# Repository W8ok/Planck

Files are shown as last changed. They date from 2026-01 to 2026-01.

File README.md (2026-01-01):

## Planck - My tiny programmable blinking LED circuit

My autism decided to get into homebrew computing, but i didnt know where to start with actual circuits.  
So I decided to go as simple as possible while keeping it pretty.  
This idea lead to this project and its future comings.  
The plan was to make a series of projects to slowly expand on making small "computer" systems with simple building blocks.  
For this first project those building blocks was just discrete components.  

The circuit is made from a simple clock running at about 1Hz feeding into two D-Flipflops acting as a 2-bit counter.  
This 2-bit output is fed into a multiplexer circuit which then provides power to the corresponding 4-bit diode-matrix ROM.  
The ROM is programmed by inserting diodes in specific positions to create the desired LED blink pattern.  
All in all, a splendid little passion project of mine.  

# Goals
Make a simple system using discrete components to program an LED blink sequence.  
Build it up on a PCB of some kind to hang on my wall for pretty kinetic art.  

# Status
Circuit - Finished  
PCB - Finished example (May make a better one eventually)  
Physical build - No (Only done on breadboard during design phase)  

# Schematic
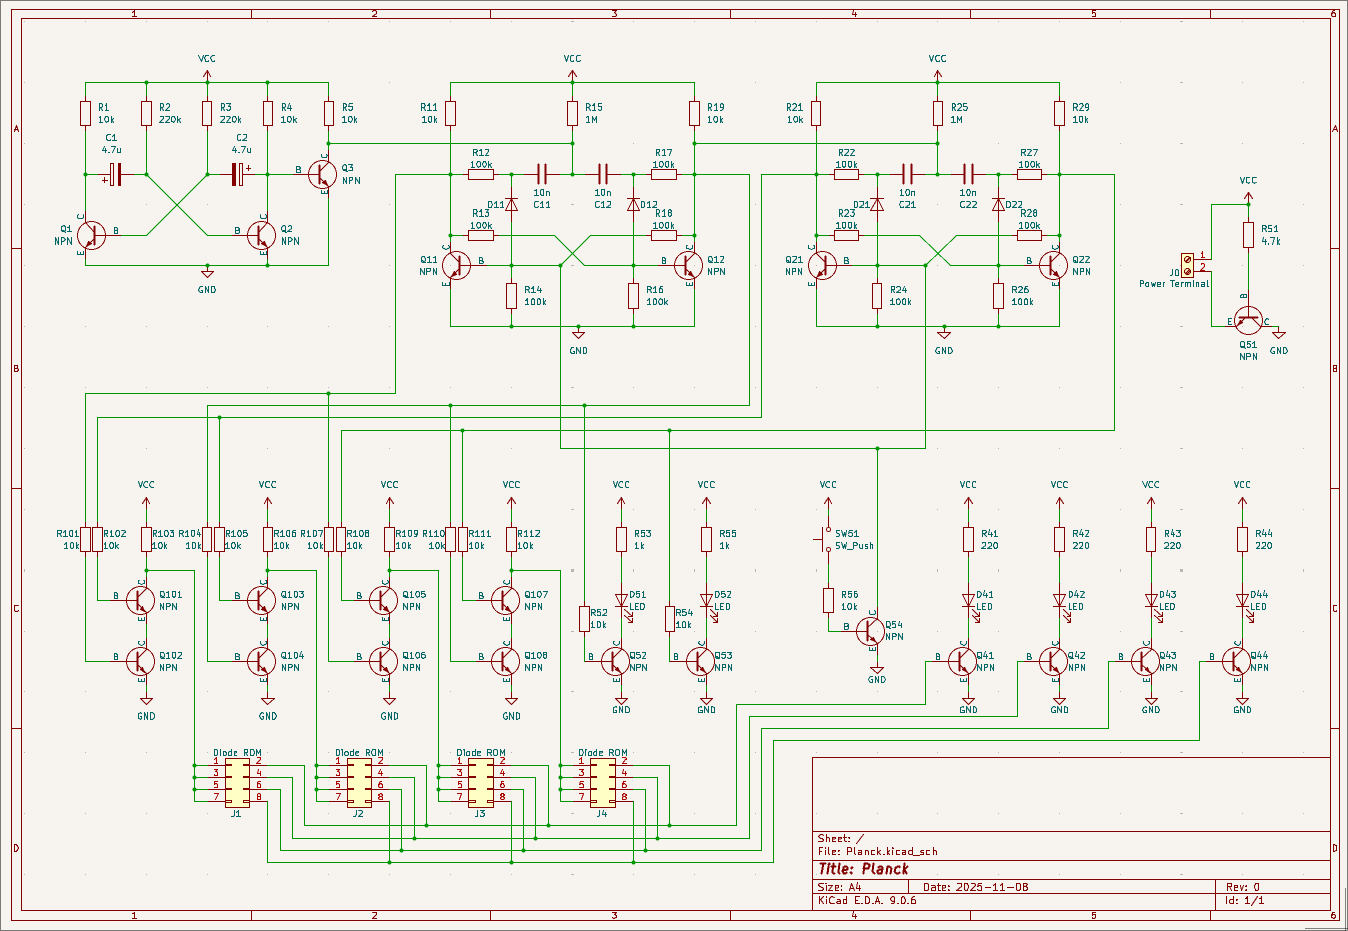
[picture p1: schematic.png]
Schematic


# Components
It is possible i miscounted, but im pretty sure i got it right  
|**Component**|**Value**|**Quantity**|**Notes**|
|:---|:---|:---|:---|
|**Resistors**|`220`|4||
||`1k`|2||
||`4.7k`|1||
||`10k`|22||
||`100k`|12||
||`1M`|2||
|**Capacitors**|`10n`|4||
||`4.7u`|2|I used polarized but not strictly needed|
|**Transistors**|`NPN`|23|2n2222 worked just fine|
|**Diodes**|`Diode`|4+16|16 for the diode ROM|
||`LED`|6|I used 2 green for address and 4 red for output|
|**Connectors**|`2x4`|4|This is where the diodes are used to program the ROM|

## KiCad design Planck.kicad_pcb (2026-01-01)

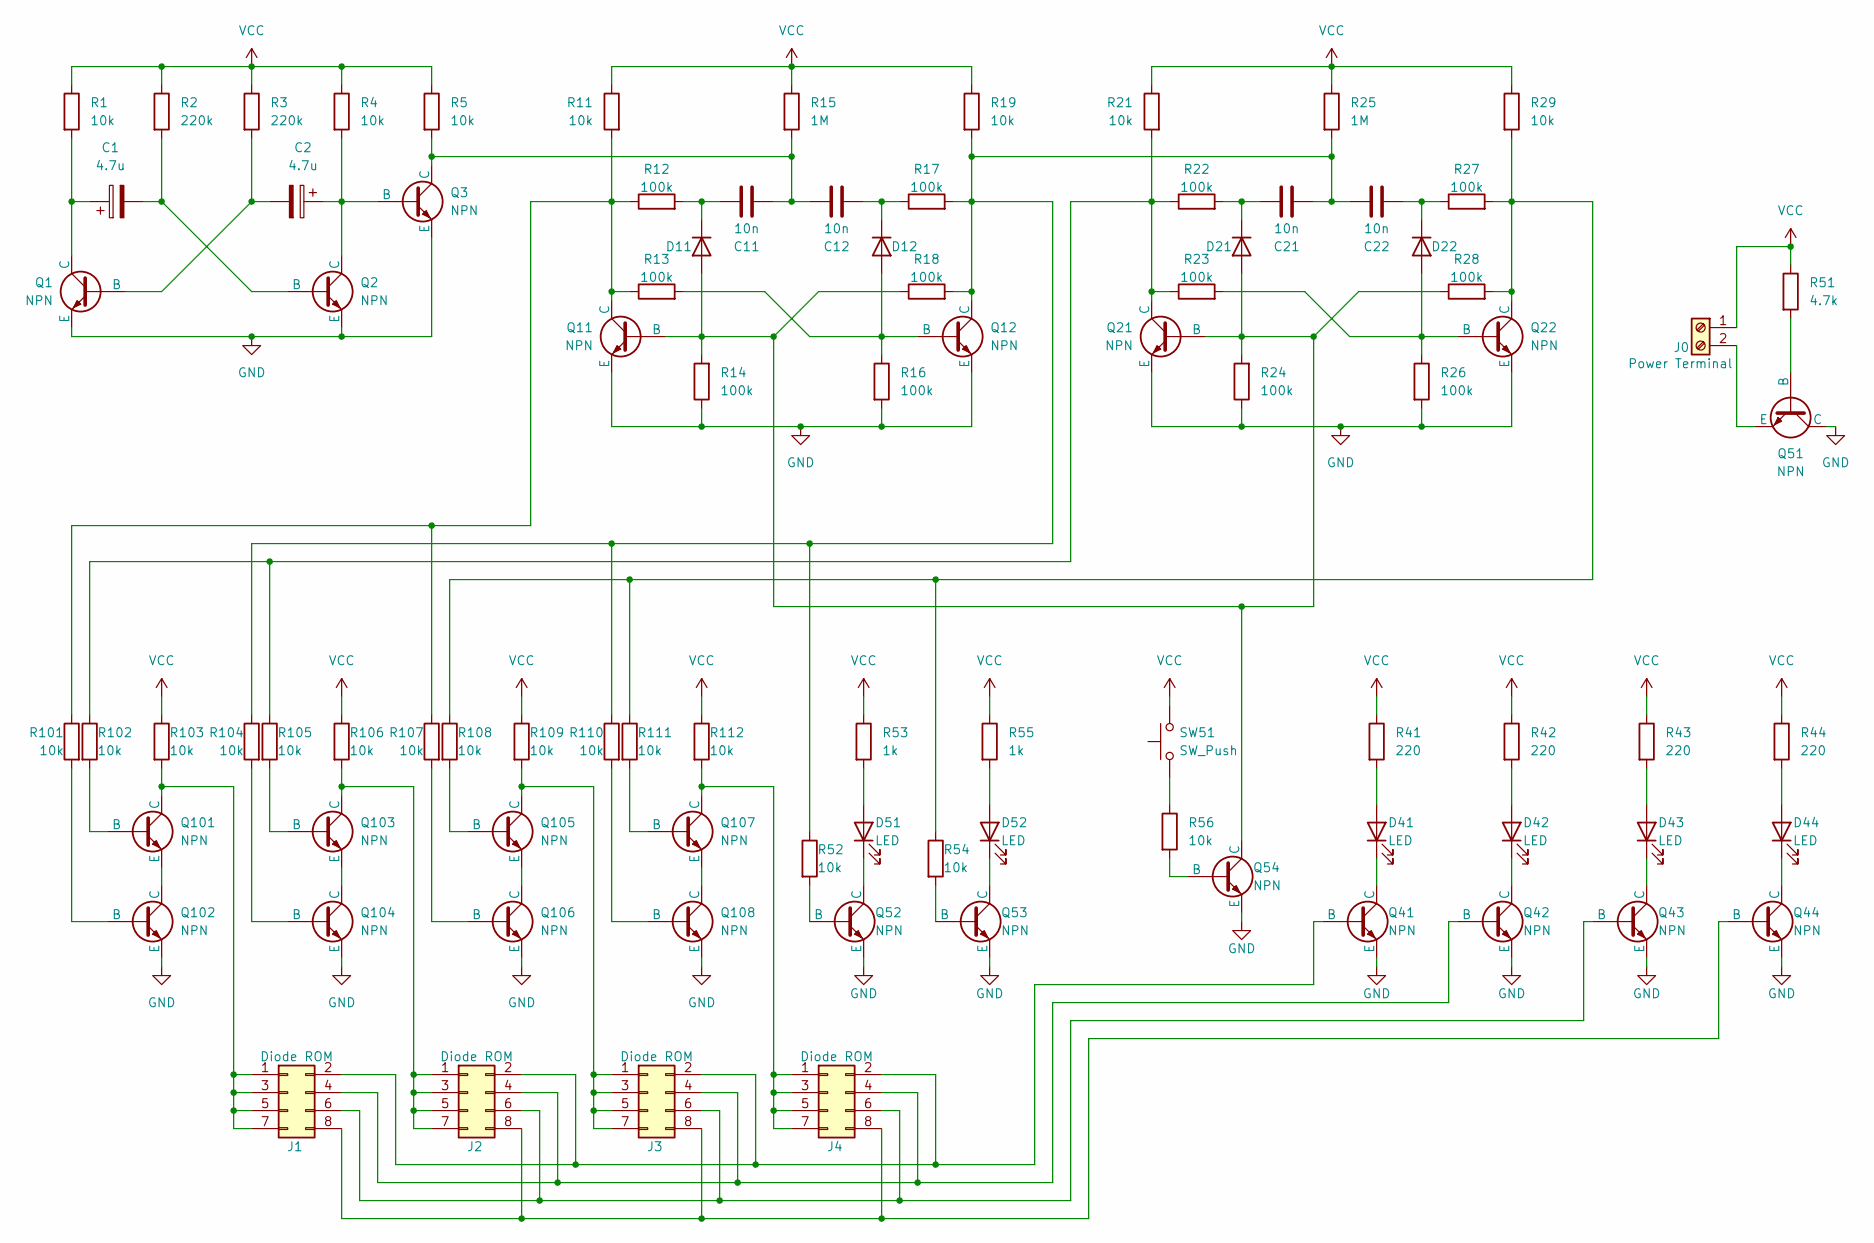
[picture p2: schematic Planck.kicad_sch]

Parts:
C1, C2: 4.7u; CP_Radial_D5.0mm_P2.50mm
C11, C12, C21, C22: 10n; C_Disc_D3.0mm_W2.0mm_P2.50mm
D11, D12, D21, D22: D; D_DO-34_SOD68_P7.62mm_Horizontal
D41, D42, D43, D44, D51, D52: LED; LED_D5.0mm
J0: Power Terminal; TerminalBlock_MaiXu_MX126-5.0-02P_1x02_P5.00mm
J1, J2, J3, J4: Diode ROM; PinHeader_2x04_P2.54mm_Vertical
Q1, Q2, Q3, Q11, Q12, Q21, Q22, Q41, Q42, Q43, Q44, Q51, Q52, Q53, Q54, Q101, Q102, Q103, Q104, Q105, Q106, Q107, Q108: NPN; TO-92
R1, R4, R5, R11, R19, R21, R29, R52, R54, R56, R101, R102, R103, R104, R105, R106, R107, R108, R109, R110, R111, R112: 10k; R_Axial_DIN0204_L3.6mm_D1.6mm_P5.08mm_Horizontal
R2, R3: 220k; R_Axial_DIN0204_L3.6mm_D1.6mm_P5.08mm_Horizontal
R12, R13, R14, R16, R17, R18, R22, R23, R24, R26, R27, R28: 100k; R_Axial_DIN0204_L3.6mm_D1.6mm_P5.08mm_Horizontal
R15, R25: 1M; R_Axial_DIN0204_L3.6mm_D1.6mm_P5.08mm_Horizontal
R41, R42, R43, R44: 220; R_Axial_DIN0204_L3.6mm_D1.6mm_P5.08mm_Horizontal
R51: 4.7k; R_Axial_DIN0204_L3.6mm_D1.6mm_P5.08mm_Horizontal
R53, R55: 1k; R_Axial_DIN0204_L3.6mm_D1.6mm_P5.08mm_Horizontal
SW51: SW_Push; SW_PUSH_6mm

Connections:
GND: Q1.3 (E), Q2.3 (E), Q3.3 (E), Q11.3 (E), Q12.3 (E), Q21.3 (E), Q22.3 (E), Q41.3 (E), Q42.3 (E), Q43.3 (E), Q44.3 (E), Q51.1 (C), Q52.3 (E), Q53.3 (E), Q54.3 (E), Q102.3 (E), Q104.3 (E), Q106.3 (E), Q108.3 (E), R14.1, R16.2, R24.1, R26.2
unnamed: D11.2 (A), D21.2 (A), Q11.2 (B), Q21.2 (B), Q54.1 (C), R14.2, R18.1, R24.2, R28.1
unnamed: C11.1, D11.1 (K), R12.2
unnamed: D12.2 (A), Q12.2 (B), R13.2, R16.1
unnamed: C12.2, D12.1 (K), R17.1
unnamed: C21.1, D21.1 (K), R22.2
unnamed: D22.2 (A), Q22.2 (B), R23.2, R26.1
unnamed: C22.2, D22.1 (K), R27.1
unnamed: D41.2 (A), R41.2
unnamed: D41.1 (K), Q41.1 (C)
unnamed: D42.2 (A), R42.2
unnamed: D42.1 (K), Q42.1 (C)
unnamed: D43.2 (A), R43.2
unnamed: D43.1 (K), Q43.1 (C)
unnamed: D44.2 (A), R44.2
unnamed: D44.1 (K), Q44.1 (C)
unnamed: D51.2 (A), R53.2
unnamed: D51.1 (K), Q52.1 (C)
unnamed: D52.2 (A), R55.2
unnamed: D52.1 (K), Q53.1 (C)
unnamed: J0.2, Q51.3 (E)
unnamed: J1.1, J1.3, J1.5, J1.7, Q101.1 (C), R103.2
unnamed: J1.2, J2.2, J3.2, J4.2, Q41.2 (B)
unnamed: J1.4, J2.4, J3.4, J4.4, Q42.2 (B)
unnamed: J1.6, J2.6, J3.6, J4.6, Q43.2 (B)
unnamed: J1.8, J2.8, J3.8, J4.8, Q44.2 (B)
unnamed: J2.1, J2.3, J2.5, J2.7, Q103.1 (C), R106.2
unnamed: J3.1, J3.3, J3.5, J3.7, Q105.1 (C), R109.2
unnamed: J4.1, J4.3, J4.5, J4.7, Q107.1 (C), R112.2
unnamed: C2.2, Q1.2 (B), R3.2
unnamed: C1.1, Q1.1 (C), R1.2
unnamed: C1.2, Q2.2 (B), R2.2
unnamed: C2.1, Q2.1 (C), Q3.2 (B), R4.2
unnamed: C11.2, C12.1, Q3.1 (C), R5.2, R15.2
unnamed: Q11.1 (C), R11.2, R12.1, R13.1, R101.1, R107.1
unnamed: C21.2, C22.1, Q12.1 (C), R17.2, R18.2, R19.2, R25.2, R52.1, R104.1, R110.1
unnamed: Q21.1 (C), R21.2, R22.1, R23.1, R102.1, R105.1
unnamed: Q22.1 (C), R27.2, R28.2, R29.2, R54.1, R108.1, R111.1
unnamed: Q51.2 (B), R51.2
unnamed: Q52.2 (B), R52.2
unnamed: Q53.2 (B), R54.2
unnamed: Q54.2 (B), R56.2
unnamed: Q101.2 (B), R102.2
unnamed: Q101.3 (E), Q102.1 (C)
unnamed: Q102.2 (B), R101.2
unnamed: Q103.2 (B), R105.2
unnamed: Q103.3 (E), Q104.1 (C)
unnamed: Q104.2 (B), R104.2
unnamed: Q105.2 (B), R108.2
unnamed: Q105.3 (E), Q106.1 (C)
unnamed: Q106.2 (B), R107.2
unnamed: Q107.2 (B), R111.2
unnamed: Q107.3 (E), Q108.1 (C)
unnamed: Q108.2 (B), R110.2
unnamed: R56.1, SW51.1
VCC: J0.1, R1.1, R2.1, R3.1, R4.1, R5.1, R11.1, R15.1, R19.1, R21.1, R25.1, R29.1, R41.1, R42.1, R43.1, R44.1, R51.1, R53.1, R55.1, R103.1, R106.1, R109.1, R112.1, SW51.2

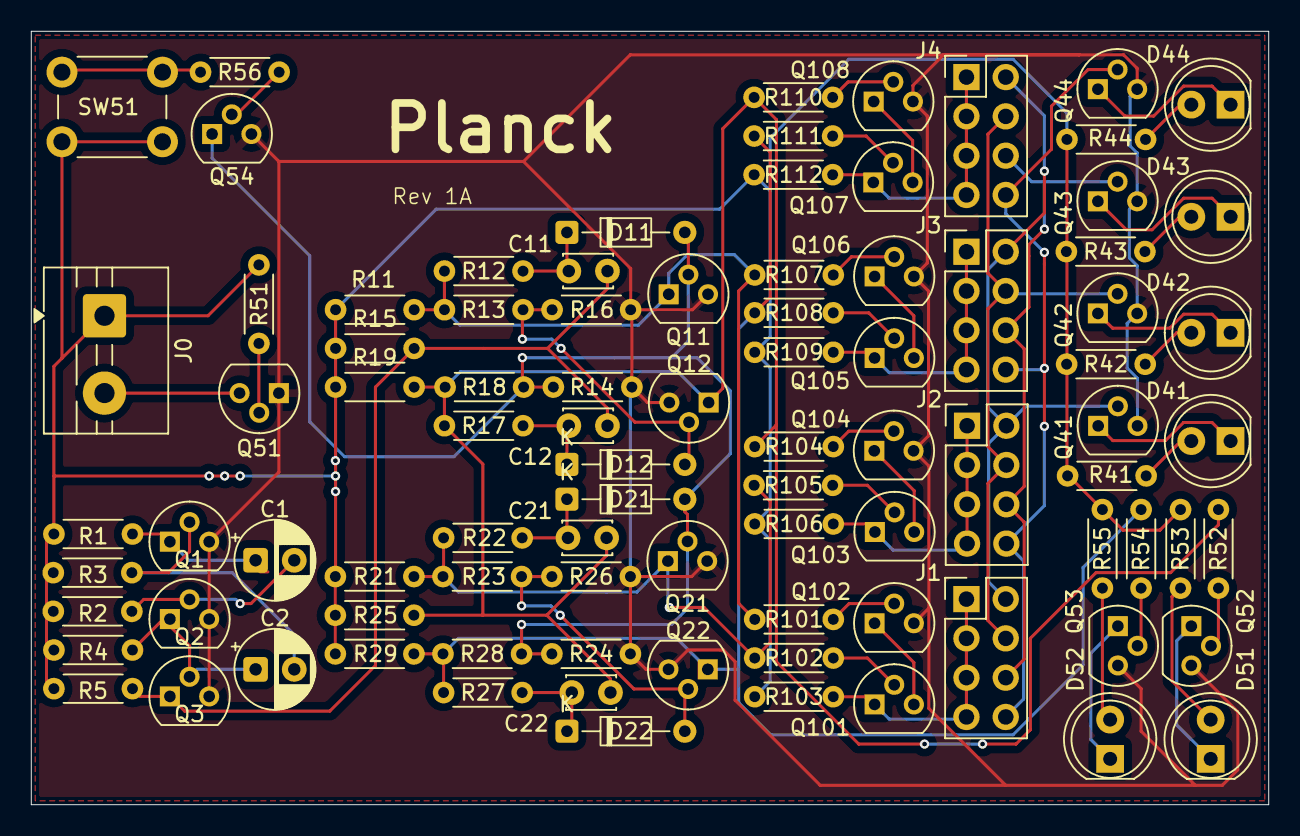
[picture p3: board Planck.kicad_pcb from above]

Board: 2 copper layers, 80.0 x 50.0 mm, 90 parts (0 on the bottom side), 56 nets.
